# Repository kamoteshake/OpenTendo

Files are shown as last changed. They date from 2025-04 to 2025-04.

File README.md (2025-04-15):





<br />

<p align="center">
  OSHW logo
</p>

# Open 'Tendo
An Open-Source HardWare (OSHW) recreation of the original 1985 Front-Loading NES motherboard.

## Note on RGB and HDMI

Neither RGB nor HDMI video output were or are a goal of the OpenTendo project, the goal was/is documentation and preservation, and the project was an exercise in reverse engineering. As such "improved" video outputs will not be added to OpenTendo.

NESRGB and Hi-Def NES can be installed as normal, but will not be incorporated into the OpenTendo PCB

## Repository Structure
### Branches
| Branch | Description |
| --- | --- |
| master | Latest revision of OpenTendo. This is a almost 1:1 of the OEM NES. |
| modded | Modded version of the latest revision (`master`). This houses any modification that is not in the OEM NES. |
| vX.X | Previous revisions of OpenTendo. (*ex.* v1.3) |
| vX.X_modded | Modded version of a previous revision. (*ex.* v1.3_modded) |

### File Structure
```
.
├── BOM              # Contains the bill of materials.
├── Board Files      # Contains all files necessary to open the project in KiCad.
|   └── Libraries    # Contains a library of all of the custom footprints used on the board.
├── Scans            # Contains the scans of the OEM NES board.
└── Schematics       # Contains schematics for the OEM frontloading NES board revisions,
                       some schematics represent more than one revision
```

The gerber files required to order PCBs can be found under [releases](https://github.com/Redherring32/OpenTendo/releases).

## Recommended PCB specs
* 2 layers

* 119mmx196mm

* 1.6mm thickness

* HASL or ENiG surface finish

* And any color you want!

> [!IMPORTANT]
> OpenTendo have some solder mask overlapping the edge connector to secure the pads and the thin traces. Some fabricators might see this as an error and might try to fix it.
>
> We recommend leaving a note saying that the solder mask overlap on the edge connector is intentional and NOT an error when ordering the PCB.

Board Front

The design is as true to the original board as possible, with subtle changes where needed to compensate for outdated/unsourcable parts,
as well as some improvements. (Expansion audio enabled, and other minor changes)

Since this project is open-source you may do as you like with it, whether that is to make boards for personal use, sell replacement NES boards, or to use the provided info for further custom PCB work/designs.

I am not in any way affiliated with Nintendo, I'm just doing this in my free time as a stepping stone into further Reverse Engineering work.

>[!NOTE]
> Please check the [BOM](./BOM#from-the-oem-nes) for the list of components needed from the OEM NES

## Modifications
* Uses the `R15` to enable the Expansion Audio.
* Added tapping points for left and right audio channels.
* Added tapping point for `RST`.
* Added a JST-PH 5 pin 2mm pitch footprint as an alternative for the `P6` connector.
* Added an SOIC footprint for the SRAMs.

## License

Licensed under
the TAPR Open Hardware License (www.tapr.org/OHL)

©Redherring32 2019-2024

## Credits
*=Lockster=* - Helping me tremendously along the way, keeping me from going insane, and cleaning up/helping with the final schematic. 

*Krzysiobal* - Putting together the NES-CPU-11 schematic that my schematic is largely referrenced against.

*[Muramasa](https://www.muramasaentertainment.com/)* - Ported to KiCad v8, PCB clean up, and fixing the EXP port footprint.

*[Kamoteshake](https://github.com/kamoteshake)* - Schematic clean up and fixing the EXP port footprint.

And to all of the awesome people in the NES scene, I wouldn't have been able to do this without the awesome work that some very clever people did before I got here.

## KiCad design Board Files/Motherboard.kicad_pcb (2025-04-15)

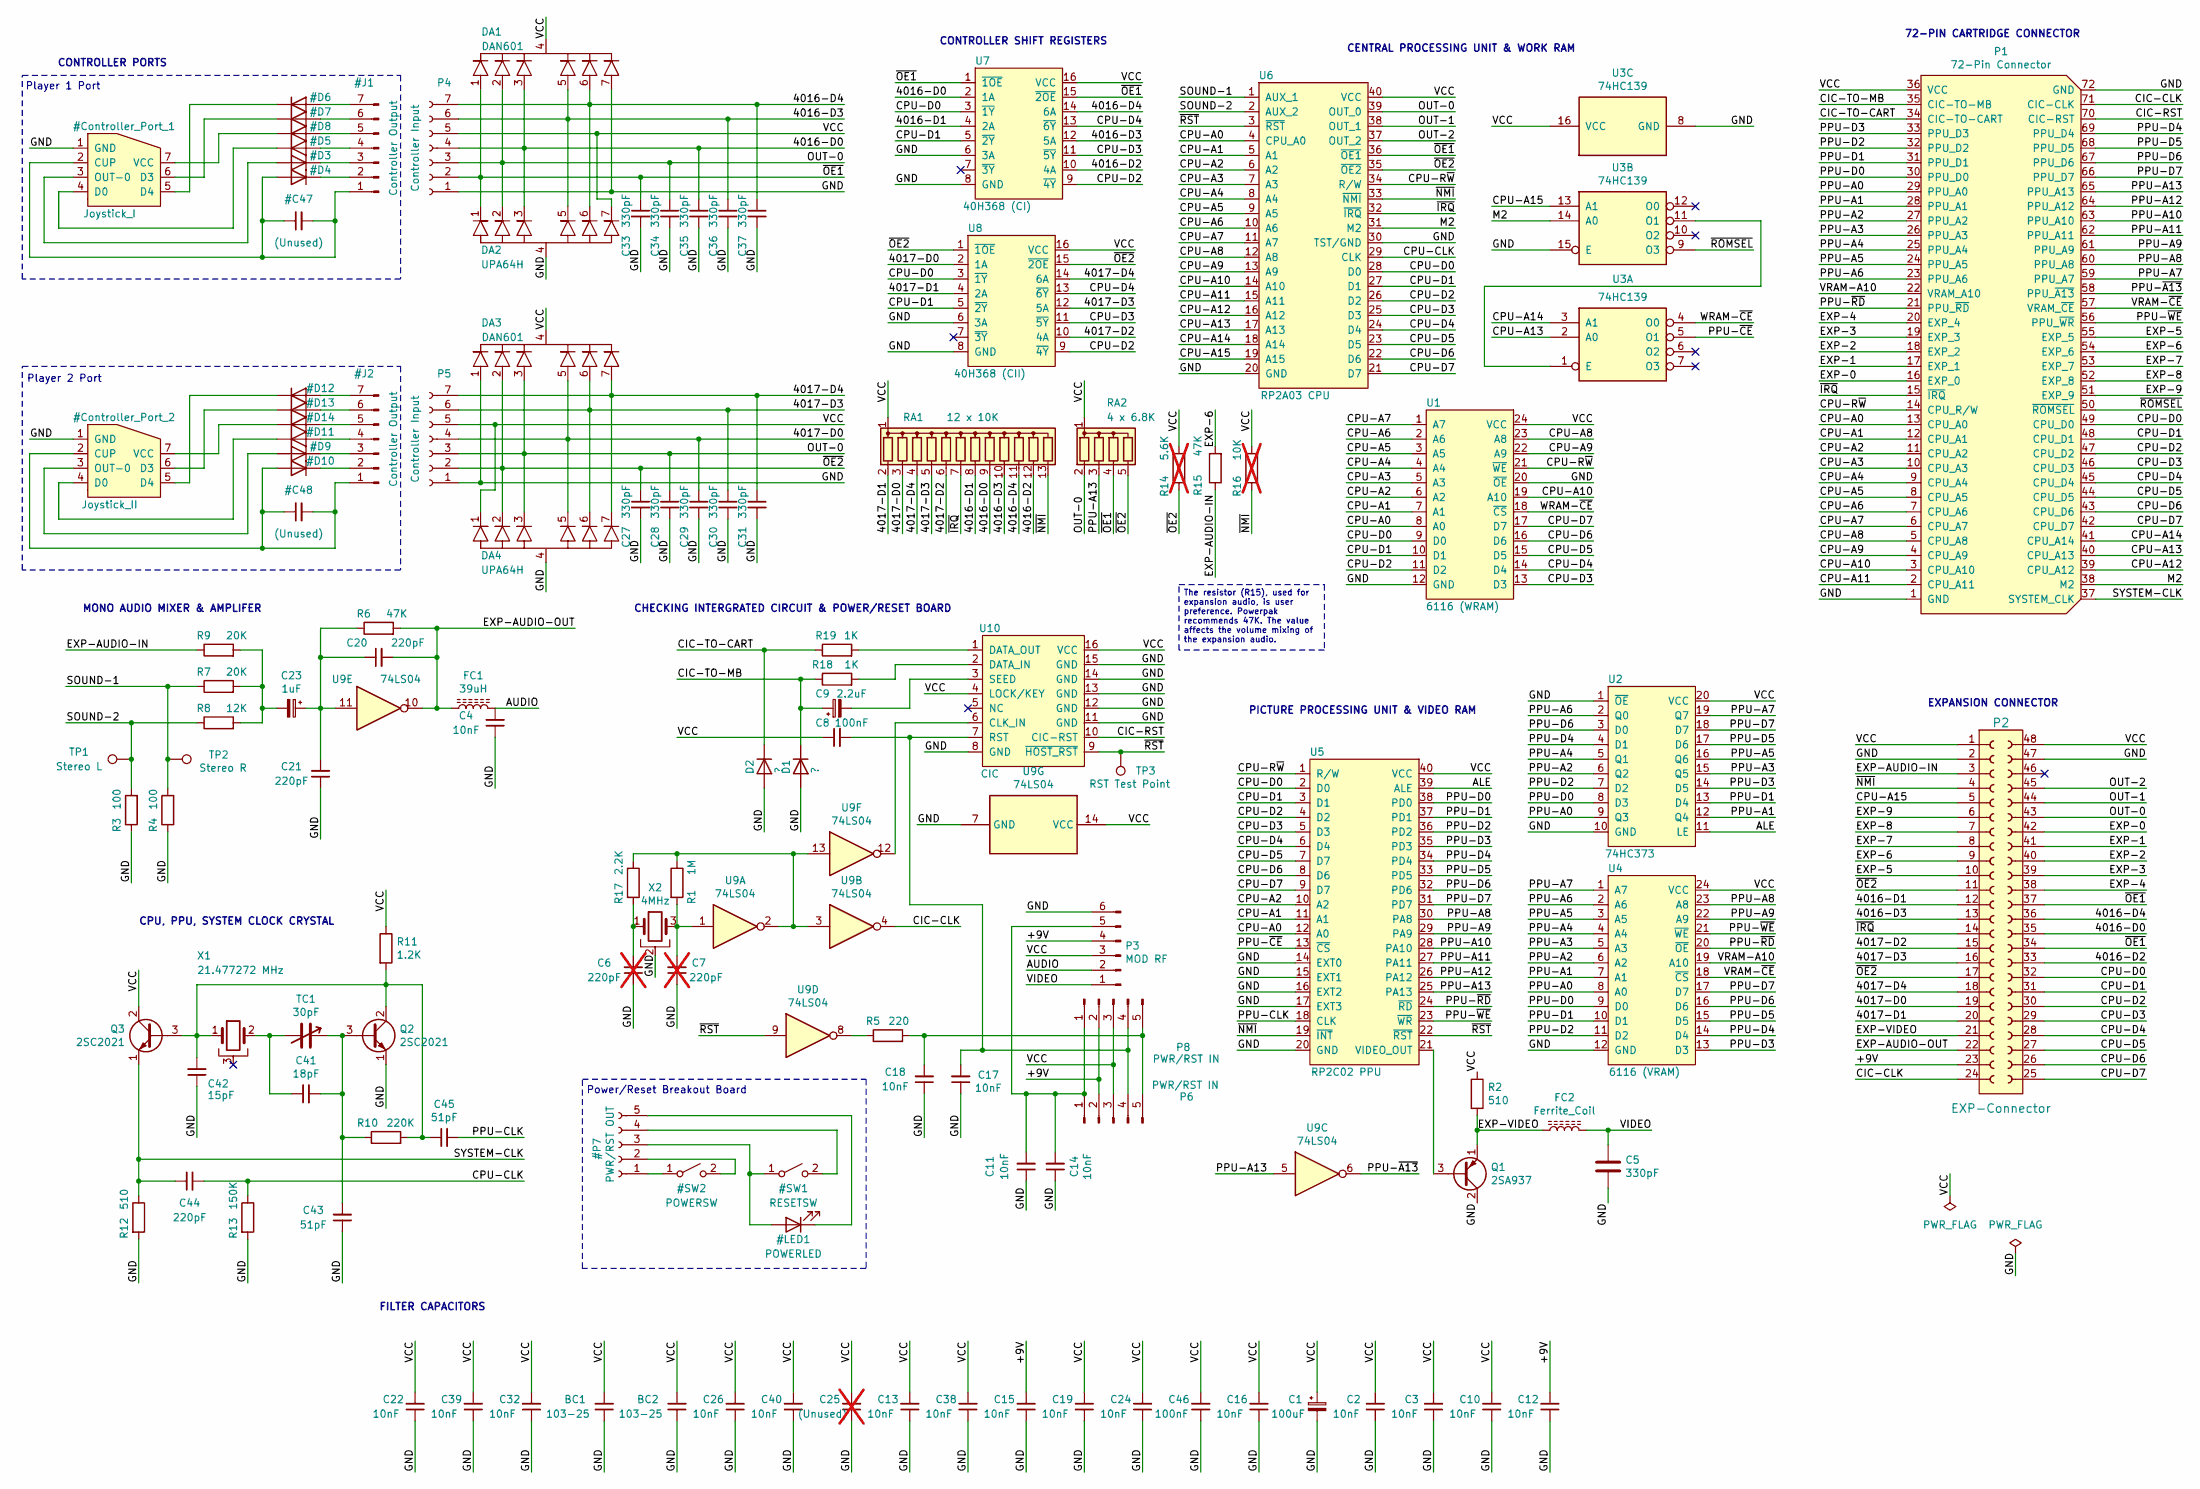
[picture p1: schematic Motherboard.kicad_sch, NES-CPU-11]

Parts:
BC1, BC2: 103-25; C_Disc_D6.0mm_W2.5mm_P5.00mm
C1: 100uF; CP_Radial_D5.0mm_P2.50mm
C2, C3, C4, C10, C11, C12, C13, C14, C15, C16, C17, C18, C19, C22, C24, C26, C32, C38, C39, C40: 10nF; C_Disc_D5.0mm_W2.5mm_P5.00mm
C5: 330pF; C_Disc_D3.0mm_W2.0mm_P2.50mm
C6, C7: 220pF; C_Disc_D3.0mm_W1.6mm_P2.50mm; not fitted
C8, C46: 100nF; C_Disc_D7.0mm_W2.5mm_P5.00mm
C9: 2.2uF; CP_Radial_D5.0mm_P2.50mm
C20, C21, C44: 220pF; C_Disc_D3.0mm_W1.6mm_P2.50mm
C23: 1uF; CP_Radial_D5.0mm_P2.50mm
C25: (Unused); C_Disc_D5.0mm_W2.5mm_P5.00mm; not fitted
C27, C28, C29, C30, C31, C33, C34, C35, C36, C37: 330pF; C_Disc_D3.0mm_W1.6mm_P2.50mm
C41: 18pF; C_Disc_D3.0mm_W2.0mm_P2.50mm
C42: 15pF; C_Disc_D3.4mm_W2.1mm_P2.50mm
C43, C45: 51pF; C_Disc_D3.4mm_W2.1mm_P2.50mm
D1, D2: ?; D_DO-35_SOD27_P10.16mm_Horizontal
DA1, DA3: DAN601; R_Array_SIP7
DA2, DA4: UPA64H; R_Array_SIP7
FC1: 39uH; R_Axial_DIN0207_L6.3mm_D2.5mm_P10.16mm_Horizontal
FC2: Ferrite_Coil; R_Axial_DIN0207_L6.3mm_D2.5mm_P10.16mm_Horizontal
P1: 72-Pin Connector; NES_Edge_Connector
P2: EXP-Connector; EXP_Header
P3: MOD RF; Mod_RF
P4, P5: Controller Input; JST_PH_S7B-PH-K_1x07_P2.00mm_Horizontal
P6: PWR/RST IN; PowerReset-switch-In
P8: PWR/RST IN; JST_PH_S5B-PH-K_1x05_P2.00mm_Horizontal
Q1: 2SA937; TO-126-3_Vertical_Short
Q2, Q3: 2SC2021; TO-126-3_Vertical_Short
R1: 1M; R_Axial_DIN0207_L6.3mm_D2.5mm_P10.16mm_Horizontal
R2, R12: 510; R_Axial_DIN0207_L6.3mm_D2.5mm_P10.16mm_Horizontal
R3, R4: 100; R_Axial_DIN0207_L6.3mm_D2.5mm_P10.16mm_Horizontal
R5: 220; R_Axial_DIN0207_L6.3mm_D2.5mm_P10.16mm_Horizontal
R6, R15: 47K; R_Axial_DIN0207_L6.3mm_D2.5mm_P10.16mm_Horizontal
R7, R9: 20K; R_Axial_DIN0207_L6.3mm_D2.5mm_P10.16mm_Horizontal
R8: 12K; R_Axial_DIN0207_L6.3mm_D2.5mm_P10.16mm_Horizontal
R10: 220K; R_Axial_DIN0207_L6.3mm_D2.5mm_P10.16mm_Horizontal
R11: 1.2K; R_Axial_DIN0207_L6.3mm_D2.5mm_P10.16mm_Horizontal
R13: 150K; R_Axial_DIN0207_L6.3mm_D2.5mm_P10.16mm_Horizontal
R14: 5.6K; R_Axial_DIN0207_L6.3mm_D2.5mm_P10.16mm_Horizontal; not fitted
R16: 10K; R_Axial_DIN0207_L6.3mm_D2.5mm_P10.16mm_Horizontal; not fitted
R17: 2.2K; R_Axial_DIN0207_L6.3mm_D2.5mm_P10.16mm_Horizontal
R18, R19: 1K; R_Axial_DIN0207_L6.3mm_D2.5mm_P10.16mm_Horizontal
RA1: 12 x 10K; R_Array_SIP13
RA2: 4 x 6.8K; R_Array_SIP5
TC1: 30pF; Trimmer_Cap_THT_5_5
TP1: Stereo L; TestPoint_Pad_1.5x1.5mm
TP2: Stereo R; TestPoint_Pad_1.5x1.5mm
TP3: RST Test Point; TestPoint_Pad_1.5x1.5mm
U1: 6116 (WRAM); DIP-24_W15.24-7.62mm_SOIC-24-15.4-7.6mm
U2: 74HC373; DIP-20_W7.62mm
U3: 74HC139; DIP-16_W7.62mm
U4: 6116 (VRAM); DIP-24_W15.24-7.62mm_SOIC-24-15.4-7.6mm
U5: RP2C02 PPU; DIP-40_W15.24mm
U6: RP2A03 CPU; DIP-40_W15.24mm
U7: 40H368 (CI); DIP-16_W7.62mm
U8: 40H368 (CII); DIP-16_W7.62mm
U9: 74LS04; DIP-14_W7.62mm
U10: CIC; DIP-16_W7.62mm
X1: 21.477272 MHz; Crystal_HC49-U_Horizontal_1EP_style2
X2: 4MHz; Resonator_Murata_CSTLSxxxG-3Pin_W8.0mm_H3.0mm

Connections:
/4016-D0: C35.1, DA1.3, DA2.3, P2.35, P4.4, RA1.9 (R8), U7.2 (1A)
/4016-D1: P2.12, RA1.8 (R7), U7.4 (2A)
/4016-D2: P2.33, RA1.12 (R11), U7.10 (4A)
/4016-D3: C36.1, DA1.5, DA2.5, P2.13, P4.6, RA1.10 (R9), U7.12 (5A)
/4016-D4: C37.1, DA1.6, DA2.6, P2.36, P4.7, RA1.11 (R10), U7.14 (6A)
/4017-D0: C29.1, DA3.5, DA4.5, P2.19, P5.4, RA1.3 (R2), U8.2 (1A)
/4017-D1: P2.20, RA1.2 (R1), U8.4 (2A)
/4017-D2: P2.15, RA1.6 (R5), U8.10 (4A)
/4017-D3: C30.1, DA3.6, DA4.6, P2.16, P5.6, RA1.5 (R4), U8.12 (5A)
/4017-D4: C31.1, DA3.7, DA4.7, P2.18, P5.7, RA1.4 (R3), U8.14 (6A)
/+9V: C12.2, C15.2, P2.23, P3.4, P6.2, P8.2
/ALE: U2.11 (LE), U5.39 (ALE)
/AUDIO: C4.2, FC1.2, P3.2
/CIC-CLK: P1.71 (CIC-CLK), P2.24, U9.4
/CIC-RST: P1.70 (CIC-RST), U10.10 (CIC-RST)
/CIC-TO-CART: D2.1 (K), P1.34 (CIC-TO-CART), R19.1
/CIC-TO-MB: C9.1, D1.1 (K), P1.35 (CIC-TO-MB), R18.1
/CPU-A0: P1.13 (CPU_A0), U1.8 (A0), U5.12 (A0), U6.4 (CPU_A0)
/CPU-A1: P1.12 (CPU_A1), U1.7 (A1), U5.11 (A1), U6.5 (A1)
/CPU-A2: P1.11 (CPU_A2), U1.6 (A2), U5.10 (A2), U6.6 (A2)
/CPU-A3: P1.10 (CPU_A3), U1.5 (A3~), U6.7 (A3)
/CPU-A4: P1.9 (CPU_A4), U1.4 (A4~), U6.8 (A4)
/CPU-A5: P1.8 (CPU_A5), U1.3 (A5~), U6.9 (A5)
/CPU-A6: P1.7 (CPU_A6), U1.2 (A6~), U6.10 (A6)
/CPU-A7: P1.6 (CPU_A7), U1.1 (A7), U6.11 (A7)
/CPU-A8: P1.5 (CPU_A8), U1.23 (A8), U6.12 (A8)
/CPU-A9: P1.4 (CPU_A9), U1.22 (A9), U6.13 (A9)
/CPU-A10: P1.3 (CPU_A10), U1.19 (A10), U6.14 (A10)
/CPU-A11: P1.2 (CPU_A11), U6.15 (A11)
/CPU-A12: P1.39 (CPU_A12), U6.16 (A12)
/CPU-A13: P1.40 (CPU_A13), U3.2 (A0), U6.17 (A13)
/CPU-A14: P1.41 (CPU_A14), U3.3 (A1), U6.18 (A14)
/CPU-A15: P2.5, U3.13 (A1), U6.19 (A15)
/CPU-CLK: C44.2, R13.1, U6.29 (CLK)
/CPU-D0: P1.49 (CPU_D0), P2.32, U1.9 (D0), U5.2 (D0), U6.28 (D0), U7.3 (~1Y), U8.3 (~1Y)
/CPU-D1: P1.48 (CPU_D1), P2.31, U1.10 (D1), U5.3 (D1), U6.27 (D1), U7.5 (~2Y), U8.5 (~2Y)
/CPU-D2: P1.47 (CPU_D2), P2.30, U1.11 (D2), U5.4 (D2), U6.26 (D2), U7.9 (~4Y), U8.9 (~4Y)
/CPU-D3: P1.46 (CPU_D3), P2.29, U1.13 (D3), U5.5 (D3), U6.25 (D3), U7.11 (~5Y), U8.11 (~5Y)
/CPU-D4: P1.45 (CPU_D4), P2.28, U1.14 (D4), U5.6 (D4), U6.24 (D4), U7.13 (~6Y), U8.13 (~6Y)
/CPU-D5: P1.44 (CPU_D5), P2.27, U1.15 (D5), U5.7 (D7), U6.23 (D5)
/CPU-D6: P1.43 (CPU_D6), P2.26, U1.16 (D6), U5.8 (D6), U6.22 (D6)
/CPU-D7: P1.42 (CPU_D7), P2.25, U1.17 (D7), U5.9 (D7), U6.21 (D7)
/CPU-R~W: P1.14 (CPU_R/W), U1.21 (~WE), U5.1 (R/W), U6.34 (R/W)
/EXP-0: P1.16 (EXP_0), P2.42
/EXP-1: P1.17 (EXP_1), P2.41
/EXP-2: P1.18 (EXP_2), P2.40
/EXP-3: P1.19 (EXP_3), P2.39
/EXP-4: P1.20 (EXP_4), P2.38
/EXP-5: P1.55 (EXP_5), P2.10
/EXP-6: P1.54 (EXP_6), P2.9, R15.2
/EXP-7: P1.53 (EXP_7), P2.8
/EXP-8: P1.52 (EXP_8), P2.7
/EXP-9: P1.51 (EXP_9), P2.6
/EXP-AUDIO-IN: P2.3, R9.1, R15.1
/EXP-AUDIO-OUT: C20.2, FC1.1, P2.22, R6.2, U9.10
/EXP-VIDEO: FC2.1, P2.21, Q1.1 (E), R2.2
/GND: BC1.1, BC2.1, C1.2, C2.1, C3.1, C4.1, C5.2, C6.1, C7.1, C10.1, C11.1, C12.1, C13.1, C14.1, C15.1, C16.1, C17.1, C18.1, C19.1, C21.1, C22.1, C24.1, C25.1, C26.1, C27.2, C28.2, C29.2, C30.2, C31.2, C32.1, C33.2, C34.2, C35.2, C36.2, C37.2, C38.1, C39.1, C40.1, C42.1, C43.1, C46.1, D1.2 (A), D2.2 (A), DA1.7, DA2.4, DA3.1, DA4.4, P1.1 (GND), P1.72 (GND), P2.2, P2.47, P3.6, P4.1, P5.1, Q1.2 (C), Q2.1 (E), R3.1, R4.1, R12.2, R13.2, U1.12 (GND~), U1.20 (~OE), U2.1 (~OE), U2.10 (GND), U3.8 (GND), U3.15 (E), U4.12 (GND~), U5.14 (EXT0), U5.15 (EXT1), U5.16 (EXT2), U5.17 (EXT3), U5.20 (GND), U6.20 (GND), U6.30 (TST/GND), U7.6 (3A), U7.8 (GND), U8.6 (3A), U8.8 (GND), U9.7 (GND), U10.8 (GND), U10.11 (GND), U10.12 (GND), U10.13 (GND), U10.14 (GND), U10.15 (GND), X2.2
/M2: P1.38 (M2), U3.14 (A0), U6.31 (M2)
/OUT-0: C28.1, C34.1, DA1.2, DA2.2, DA3.3, DA4.3, P2.43, P4.3, P5.3, RA2.2 (R1), U6.39 (OUT_0)
/OUT-1: P2.44, U6.38 (OUT_1)
/OUT-2: P2.45, U6.37 (OUT_2)
/PPU-A0: P1.29 (PPU_A0), U2.9 (Q3), U4.8 (A0)
/PPU-A1: P1.28 (PPU_A1), U2.12 (Q4), U4.7 (A1)
/PPU-A2: P1.27 (PPU_A2), U2.6 (Q2), U4.6 (A2)
/PPU-A3: P1.26 (PPU_A3), U2.15 (Q5), U4.5 (A3~)
/PPU-A4: P1.25 (PPU_A4), U2.5 (Q1), U4.4 (A4~)
/PPU-A5: P1.24 (PPU_A5), U2.16 (Q6), U4.3 (A5~)
/PPU-A6: P1.23 (PPU_A6), U2.2 (Q0), U4.2 (A6~)
/PPU-A7: P1.59 (PPU_A7), U2.19 (Q7), U4.1 (A7)
/PPU-A8: P1.60 (PPU_A8), U4.23 (A8), U5.30 (PA8)
/PPU-A9: P1.61 (PPU_A9), U4.22 (A9), U5.29 (PA9)
/PPU-A10: P1.63 (PPU_A10), U5.28 (PA10)
/PPU-A11: P1.62 (PPU_A11), U5.27 (PA11)
/PPU-A12: P1.64 (PPU_A12), U5.26 (PA12)
/PPU-A13: P1.65 (PPU_A13), RA2.3 (R2), U5.25 (PA13), U9.5
/PPU-CLK: C45.2, U5.18 (CLK)
/PPU-D0: P1.30 (PPU_D0), U2.8 (D3), U4.9 (D0), U5.38 (PD0)
/PPU-D1: P1.31 (PPU_D1), U2.13 (D4), U4.10 (D1), U5.37 (PD1)
/PPU-D2: P1.32 (PPU_D2), U2.7 (D2), U4.11 (D2), U5.36 (PD2)
/PPU-D3: P1.33 (PPU_D3), U2.14 (D5), U4.13 (D3), U5.35 (PD3)
/PPU-D4: P1.69 (PPU_D4), U2.4 (D1), U4.14 (D4), U5.34 (PD4)
/PPU-D5: P1.68 (PPU_D5), U2.17 (D6), U4.15 (D5), U5.33 (PD5)
/PPU-D6: P1.67 (PPU_D6), U2.3 (D0), U4.16 (D6), U5.32 (PD6)
/PPU-D7: P1.66 (PPU_D7), U2.18 (D7), U4.17 (D7), U5.31 (PD7)
/PPU-~A13: P1.58 (PPU_~A13), U9.6
/PPU-~CE: U3.5 (O1), U5.13 (~CS)
/PPU-~RD: P1.21 (PPU_~RD), U4.20 (~OE), U5.24 (~RD)
/PPU-~WE: P1.56 (PPU_~WR), U4.21 (~WE), U5.23 (~WR)
/SOUND-1: R4.2, R7.1, TP2.1, U6.1 (AUX_1)
/SOUND-2: R3.2, R8.1, TP1.1, U6.2 (AUX_2)
/SYSTEM-CLK: C44.1, P1.37 (SYSTEM_CLK), Q3.1 (E), R12.1
/VCC: BC1.2, BC2.2, C1.1, C2.2, C3.2, C8.1, C10.2, C13.2, C16.2, C19.2, C22.2, C24.2, C25.2, C26.2, C32.2, C38.2, C39.2, C40.2, C46.2, DA1.4, DA2.7, DA3.4, DA4.1, P1.36 (VCC), P2.1, P2.48, P3.3, P4.5, P5.5, P6.3, P8.3, Q3.2 (C), R2.1, R11.1, R14.1, R16.1, RA1.1 (common), RA2.1 (common), U1.24 (VCC), U2.20 (VCC), U3.16 (VCC), U4.24 (VCC), U5.40 (VCC), U6.40 (VCC), U7.16 (VCC), U8.16 (VCC), U9.14 (VCC), U10.4 (LOCK/KEY), U10.16 (VCC)
/VIDEO: C5.1, FC2.2, P3.1
/VRAM-A10: P1.22 (VRAM_A10), U4.19 (A10)
/VRAM-~CE: P1.57 (VRAM_~CE), U4.18 (~CS)
/WRAM-~CE: U1.18 (~CS), U3.4 (O0)
/~IRQ: P1.15 (~IRQ), P2.14, RA1.7 (R6), U6.32 (~IRQ)
/~NMI: P2.4, R16.2, RA1.13 (R12), U5.19 (~INT), U6.33 (~NMI)
/~OE1: C33.1, DA1.1, DA2.1, P2.34, P2.37, P4.2, RA2.4 (R3), U6.36 (~OE1), U7.1 (~1OE), U7.15 (~2OE)
/~OE2: C27.1, DA3.2, DA4.2, P2.11, P2.17, P5.2, R14.2, RA2.5 (R4), U6.35 (~OE2), U8.1 (~1OE), U8.15 (~2OE)
/~ROMSEL: P1.50 (~ROMSEL), U3.9 (O3)
/~RST: TP3.1, U5.22 (~RST), U6.3 (~RST), U9.9, U10.9 (~HOST_RST)
unnamed: C6.2, R17.2, X2.1
unnamed: C7.2, R1.2, U9.1, X2.3
unnamed: C20.1, C21.2, C23.1, R6.1, U9.11
unnamed: C23.2, R7.2, R8.2, R9.2
unnamed: C41.1, TC1.2, X1.2
unnamed: C11.2, C14.2, P3.5, P6.1, P8.1
unnamed: C8.2, C17.2, P6.4, P8.4, U10.7 (RST)
unnamed: C18.2, P6.5, P8.5, R5.2
unnamed: Q1.3 (B), U5.21 (VIDEO_OUT)
unnamed: C41.2, C43.2, Q2.3 (B), R10.1, TC1.1
unnamed: C42.2, C45.1, Q2.2 (C), Q3.3 (B), R10.2, R11.2, X1.1
unnamed: R1.1, R17.1, U9.2, U9.3, U9.13
unnamed: R5.1, U9.8
unnamed: U3.1 (E), U3.11 (O1)
unnamed: U9.12, U10.6 (CLK_IN)
unnamed: R18.2, U10.2 (DATA_IN)
unnamed: R19.2, U10.1 (DATA_OUT)
unnamed: C9.2, U10.3 (SEED)

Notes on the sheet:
72-PIN CARTRIDGE CONNECTOR
MONO AUDIO MIXER & AMPLIFER
CENTRAL PROCESSING UNIT & WORK RAM
CONTROLLER PORTS
EXPANSION CONNECTOR
FILTER CAPACITORS
Player 2 Port
Player 1 Port
Power/Reset Breakout Board
CHECKING INTERGRATED CIRCUIT & POWER/RESET BOARD
PICTURE PROCESSING UNIT & VIDEO RAM
CPU, PPU, SYSTEM CLOCK CRYSTAL
CONTROLLER SHIFT REGISTERS
The resistor (R15), used for expansion audio, is user preference. Powerpak recommends 47K. The value affects the volume mixing of the expansion audio.

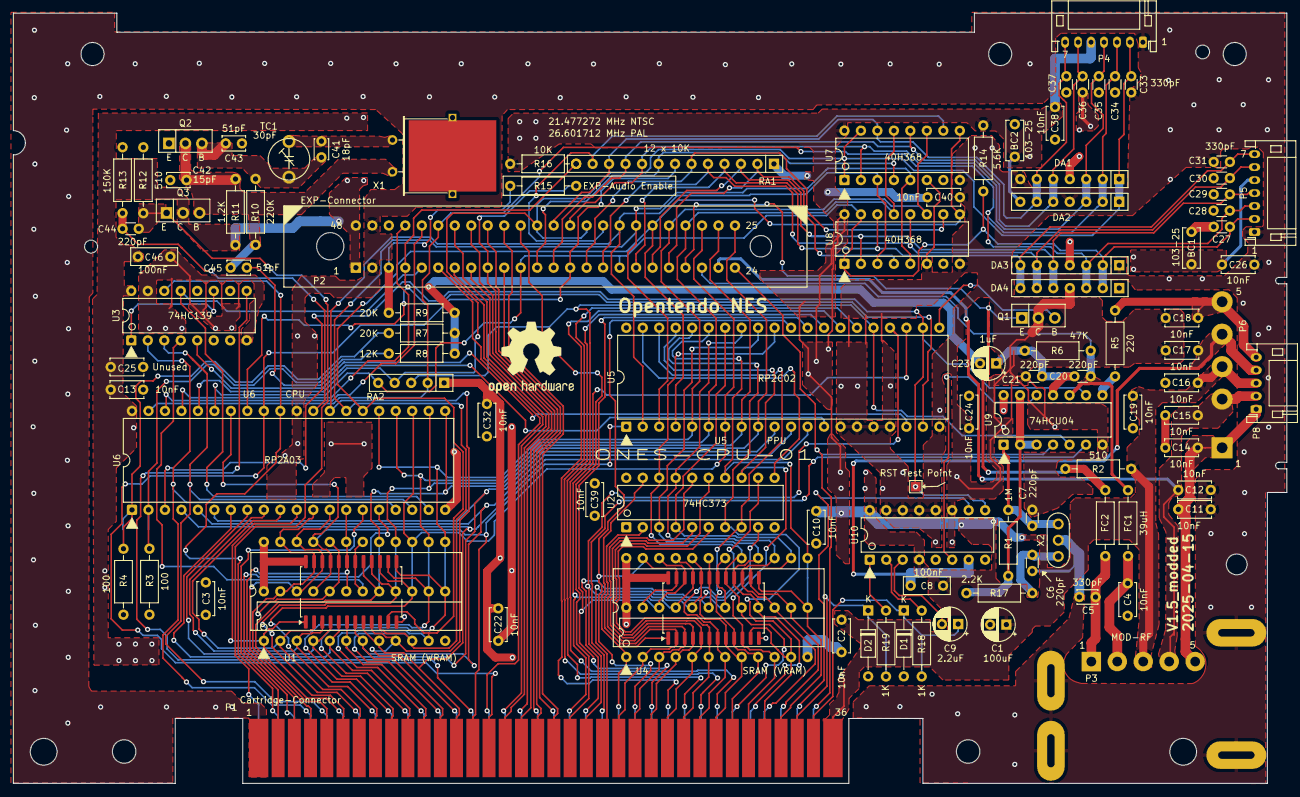
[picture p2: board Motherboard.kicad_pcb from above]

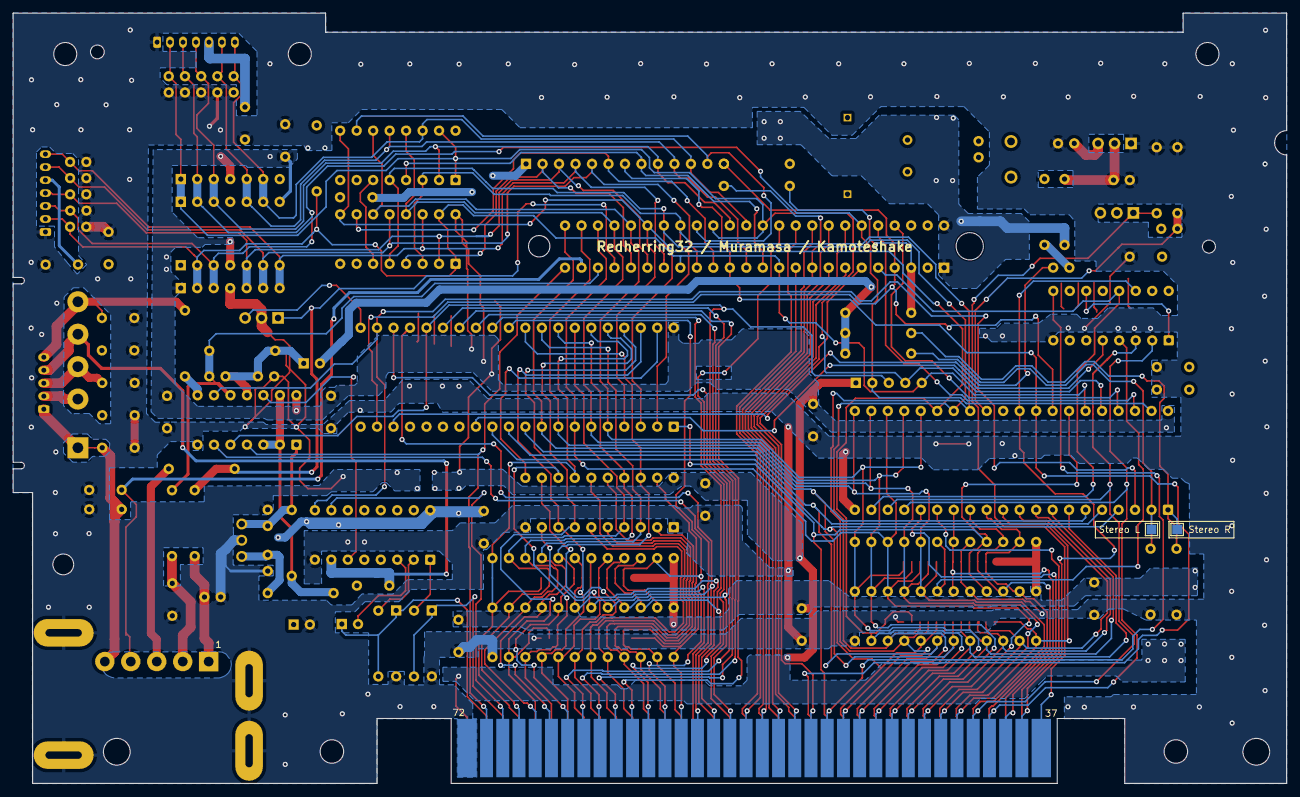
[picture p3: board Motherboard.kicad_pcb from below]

Board: 2 copper layers, 196.3 x 118.7 mm, 103 parts (2 on the bottom side), 120 nets.

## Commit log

2025-04-15 feat: port to kicad v9
    [Motherboard.kicad_pcb, Motherboard.kicad_sch]
2025-04-15 fix: diode array symbols
    [Motherboard.kicad_sch]
2025-04-15 feat: updated kicad v9 symbols
    [Motherboard.kicad_sch]
2025-04-15 fix: 74HC368 bus pin type
    [Motherboard.kicad_sch]
2025-04-15 feat: added power flag to gnd and vcc nets
    [Motherboard.kicad_sch]
2025-04-15 fix: changed ppu ext pins to passive
    [Motherboard.kicad_sch]
2025-04-15 feat: updated footprints to fix DRC errors and warnings
    [Motherboard.kicad_pcb, Motherboard.kicad_sch]
2025-04-15 chore: updated version and date on board
    [Motherboard.kicad_pcb]
2025-04-15 feat: updated interactive bom
2025-04-15 chore: generated gerber
    [Motherboard.kicad_pcb]
2025-04-15 feat: added R1 and C40 value on silkscreen
    [Motherboard.kicad_pcb]
2025-04-15 feat: updated trimmer cap footprint
    [Motherboard.kicad_pcb, Motherboard.kicad_sch]
2025-04-15 chore: updated date on board
    [Motherboard.kicad_pcb]
